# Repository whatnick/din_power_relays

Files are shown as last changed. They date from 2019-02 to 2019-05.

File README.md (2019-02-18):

# DIN Rail Format Energy Meter Base Board
## Power SMPS module
- 90v-240v AC input
- Isolated 5V output
- 600mA / 3W power rating

## Over-voltage protection/over-current protection
- 0.1A rated PTC fuse
- 300V rated TVS suppressors, x1 per-phase

## Isolation
- 5v DC-DC isolator to power metering module

## Power supply clean-up
- x2 1117 series LDO for generating 3.3v from 5V input to clean up SMPS noise

## Backup-power
- MCP73831 series floating Lipo battery charger for backup lipo battery

## AC Voltage Sampler
- x3 Voltage divider ladders with 880K + 1K total serial resistance

## AC current Sampler
- x4 2.4ohm current sense resistor based CT clamp inputs

## Relay Driver
- x4 optoisolated relay driver connectors, external power required to operate relays.

## Connectors
- 5.08mm spacing phoenix contact AC voltage connector
- Molex nanofit 2x4 type dense AC current clamp connectors

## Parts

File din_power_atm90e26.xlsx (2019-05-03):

Prj: | din_power_atm90e26.xml |  |  |  | Board Qty: | 1
Co.: |  |  |  |  | Unit Cost: | $0.00
Prj date: | 3/05/2019 10:37:13 PM |  |  |  | Total Cost: | $0.00
$ date: | 2019-05-03 22:37:15
Global Part Info
Refs | Value | Footprint | Manf# | Qty | Unit$ | Ext$
C1-C3 | 33n | Capacitors_SMD:C_0603 | CC0603KRX7R9BB333 | 3 |  | $0.00
C5-C8 | 1uF | Capacitors_SMD:C_0603 | 0603ZD105KAT2A | 4 |  | $0.00
F1 | Polyfuse | Capacitors_THT:C_Disc_D10.0mm_W2.5mm_P5.00mm | 0ZRE0012FF1C | 1 |  | $0.00
J1 | CONN_01X06 | Connectors_Phoenix:PhoenixContact_MC-G_06x5.08mm_Angled | 1759059 | 1 |  | $0.00
J2 | Conn_01x04 | Connector_JST:JST_SH_BM04B-SRSS-TB_1x04-1MP_P1.00mm_Vertical |  | 1 |  | $0.00
J3,J5 | CONN_01X08 | Connectors_Molex:Molex_NanoFit_2x04x2.50mm_Angled | 1053141108 | 2 |  | $0.00
J4 | CONN_02X18 | hi-link_smps:PCIE-36-SKT | 10018784-10210TLF | 1 |  | $0.00
L1 | Ferrite_Bead_Small | Inductors_SMD:L_1206 | AIML-1206-R27K-T | 1 |  | $0.00
R18 | 330R | Resistor_SMD:R_0603_1608Metric | 603-RC0201JR-7D330RL | 1 |  | $0.00
R1-R4,R8-R11 | 2.4R | Resistors_SMD:R_0603 | ERJ-3RQF2R4V | 8 |  | $0.00
R25-R27 | 1K | Resistors_SMD:R_0603 | CRG0603F1K0 | 3 |  | $0.00
R5-R7,R12-R17,R22-R24 | 220K | Resistors_SMD:R_1206 | CRCW1206220KFKEA | 12 |  | $0.00
RV1-RV3 | Varistor | SMD_Packages:SMD-4032 | VP3225K401R275 | 3 |  | $0.00
U1,U6-U8 | LTV-356T | Package_SO:SO-4_4.4x3.6mm_P2.54mm | LTV-356T (http://optoelectronics.liteon.com/upload/download/DS70-2001-010/S_110_LTV-356T%2020140520.pdf) | 4 |  | $0.00
U2 | L78L33_SOT89 | TO_SOT_Packages_SMD:SOT-89-3 | AP7365-33YG-13 | 1 |  | $0.00
U3 | L78L05_SOT89 | TO_SOT_Packages_SMD:SOT-89-3 | AP7365-33YG-13 | 1 |  | $0.00
U4 | Hi-Link_SMPS | hi-link_smps:HKLPM01 | HLK-PM01 | 1 |  | $0.00
U5 | dc-dc | hi-link_smps:SIP4 | ROE-0505S | 1 |  | $0.00
KiCost® v.1.0.4 (Powered by Octopart.com API)

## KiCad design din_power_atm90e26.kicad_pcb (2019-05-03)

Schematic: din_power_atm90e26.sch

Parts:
C1, C2, C3: 33n; C_0603
C5, C6, C7, C8: 1uF; C_0603
F1: Polyfuse; C_Disc_D10.0mm_W2.5mm_P5.00mm
G1: LOGO; Whatnick_logo
J1: CONN_01X06; PhoenixContact_MC-G_06x5.08mm_Angled
J2: Conn_01x04; JST_SH_BM04B-SRSS-TB_1x04-1MP_P1.00mm_Vertical
J3, J5: CONN_01X08; Molex_NanoFit_2x04x2.50mm_Angled
J4: CONN_02X18; PCIE-36-SKT
L1: Ferrite_Bead_Small; L_1206
LOGO_OSHW1: Logo_Open_Hardware_Small; OSHW-Symbol_6.7x6mm_SilkScreen
R1, R2, R3, R4, R8, R9, R10, R11: 2.4R; R_0603
R5, R6, R7, R12, R13, R14, R15, R16, R17, R22, R23, R24: 220K; R_1206
R18: 330R; R_0603_1608Metric
R25, R26, R27: 1K; R_0603
RV1, RV2, RV3: Varistor; SMD-4032
SYM1: SYM_Flash_Small; Fsilk_HV
U1, U6, U7, U8: LTV-356T; SO-4_4.4x3.6mm_P2.54mm
U2: L78L33_SOT89; SOT-89-3
U3: L78L05_SOT89; SOT-89-3
U4: Hi-Link_SMPS; HKLPM01
U5: dc-dc; SIP4

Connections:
+3.3V_ISO: C8.1, J4.8, U3.1 (OUT)
+3V3: C7.1, J4.32, U2.1 (OUT)
+5V: C6.1, J4.34, U2.3 (IN), U4.4, U5.2
+5V_ISO: C5.1, J4.9, U3.3 (IN), U5.4
/UN_IN: F1.1, U4.2
/ua_1: R5.1, R12.2
/ua_2: R12.1, R15.2
/ua_3: R15.1, R22.2
/ub_1: R6.1, R13.2
/ub_2: R13.1, R16.2
/ub_3: R16.1, R23.2
/uc_1: R7.1, R14.2
/uc_2: R14.1, R17.2
/uc_3: R17.1, R24.2
GNDA: C1.2, C2.2, C3.2, C5.2, C8.2, J4.7, L1.1, R1.1, R2.2, R3.1, R4.2, R8.1, R9.2, R10.1, R11.2, R25.1, R26.1, R27.1, U3.2 (GND), U5.3
GNDPWR: C6.2, C7.2, J4.36, R18.2, U2.2 (GND), U4.3, U5.1
IA1+: J4.11, J5.1, R1.2
IA1-: J4.13, J5.2, R2.1
IA2+: J4.27
IA2-: J4.29
IB1+: J4.15, J5.3, R8.2
IB1-: J4.17, J5.4, R9.1
IB2+: J4.31
IB2-: J4.33
IC1+: J4.19, J5.5, R3.2
IC1-: J4.21, J5.6, R4.1
IC2+: J4.35
IC2-: J4.2
IN1+: J4.23, J5.7, R10.2
IN1-: J4.25, J5.8, R11.1
IN2+: J4.4
IN2-: J4.6
LED_H1: J2.1, U1.1
LED_H2: J2.2, U6.1
LED_H3: J2.3, U7.1
LED_H4: J2.4, U8.1
LED_L: R18.1, U1.2, U6.2, U7.2, U8.2
RE1_H: J3.1, U1.4
RE1_L: J3.2, U1.3
RE2_H: J3.3, U6.4
RE2_L: J3.4, U6.3
RE3_H: J3.5, U7.4
RE3_L: J3.6, U7.3
RE4_H: J3.7, U8.4
RE4_L: J3.8, U8.3
UA: J1.1, R5.2, RV1.2
UA_SAMP: C3.1, J4.5, R22.1, R25.2
UB: J1.3, R6.2, RV2.2
UB_SAMP: C1.1, J4.3, R23.1, R26.2
UC: J1.5, R7.2, RV3.2, U4.1
UC_SAMP: C2.1, J4.1, R24.1, R27.2
UN: F1.2, J1.6, L1.2, RV1.1, RV2.1, RV3.1
VBAT: J4.30

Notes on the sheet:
Power Systems (5V)
Voltage Sampling
Current Sampling
CT Input
Connector for Metering/Processor boards - Supplies IV samples and +5V power with/without isolation
Optional N-CT1
Power Systems - dual 3.3v LDO
Optocoupler driver

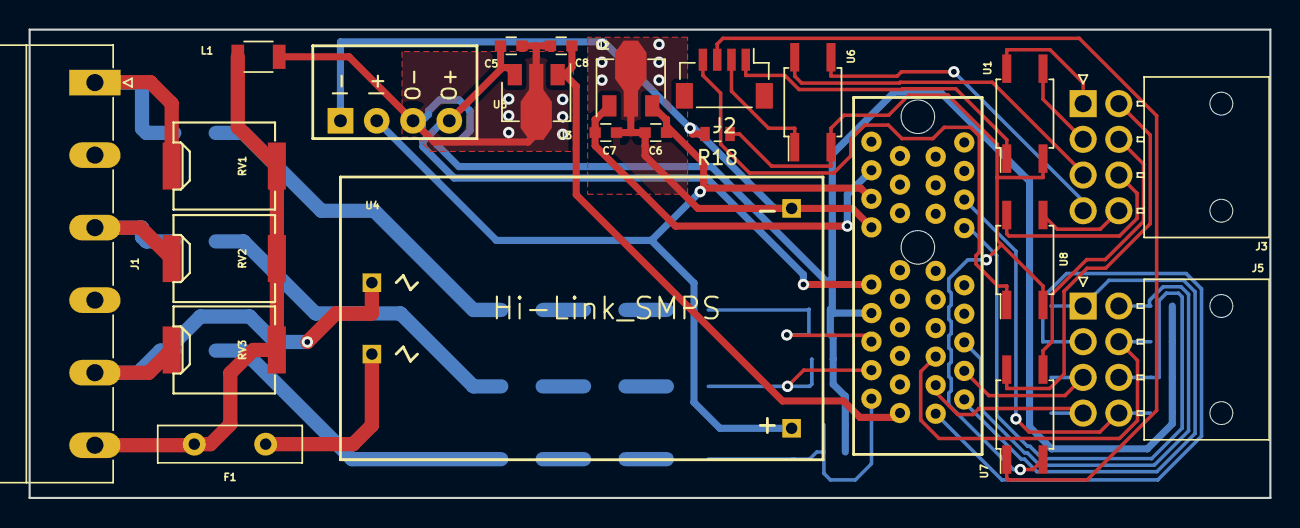
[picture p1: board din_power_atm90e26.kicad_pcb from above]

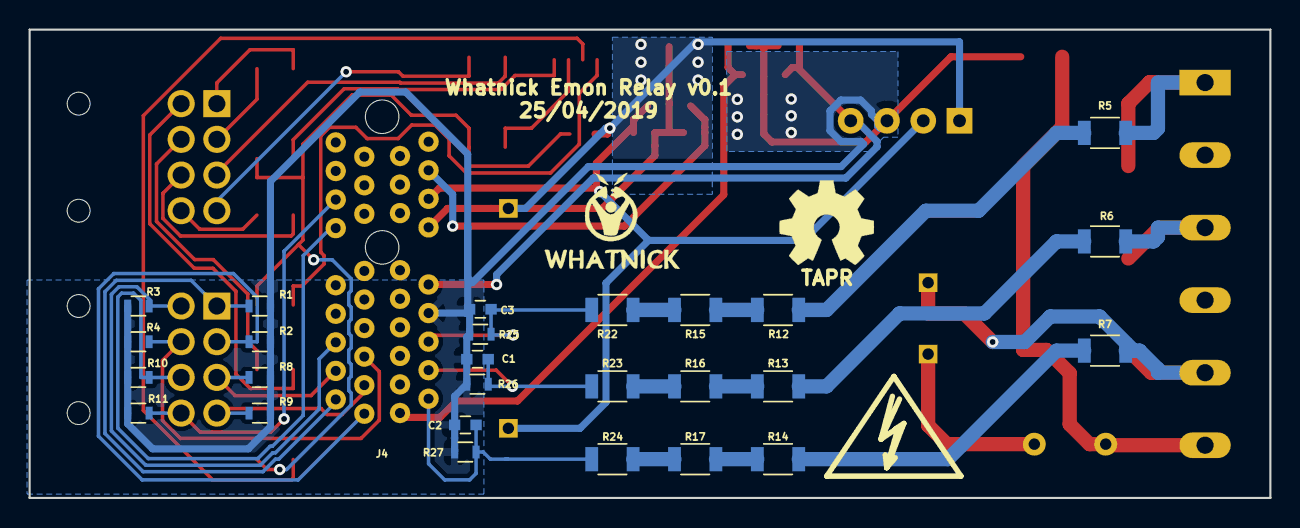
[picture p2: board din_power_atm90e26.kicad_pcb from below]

Board: 2 copper layers, 86.9 x 32.8 mm, 52 parts (30 on the bottom side), 44 nets.

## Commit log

2019-02-18 Added notes in README.md for relay driver
2019-02-18 Begin migration to relay drivers
    [din_power_atm90e26.sch]
2019-03-03 Updates links to new KiCAD libraries
    [din_power_atm90e26.kicad_pcb, din_power_atm90e26.sch]
2019-04-24 Ripped out routing and added individual optos
    [din_power_atm90e26.kicad_pcb, din_power_atm90e26.sch]
2019-05-01 Added routing for Opto-driver based PCB
    [din_power_atm90e26.kicad_pcb, din_power_atm90e26.sch]
2019-05-03 Finalize BOM and Gerbers
    [din_power_atm90e26-B.Cu.gbl, din_power_atm90e26-B.Mask.gbs, din_power_atm90e26-B.Paste.gbp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]
2019-05-03 New BOM and parts postions
    [din_power_atm90e26.xlsx]
